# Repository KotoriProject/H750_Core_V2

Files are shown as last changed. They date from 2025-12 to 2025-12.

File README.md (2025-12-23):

# Join us!🥰🥰🥰
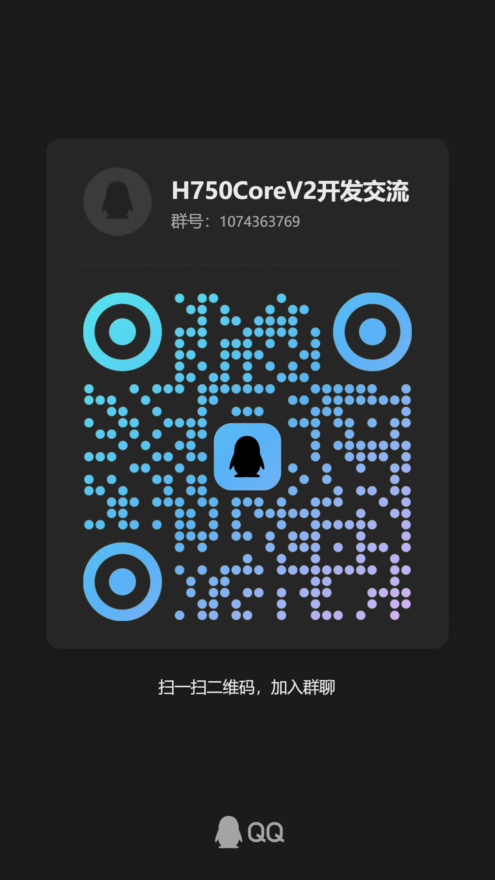
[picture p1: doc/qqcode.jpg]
qrcode
 

# STM32H750XBH6 Core V2

Feature: just mini😇only mini😡yes mini😎

lead some config/power pin like:
- PDR_ON
- BOOT0
- VREF±
- VDDA VSSA
- VCAP/VDDLDO
- VBAT

Onboard:
- 32Mbit 32bit SDRAM
- 128Mbit dual qspi flash
- HSE
- LSE
- TLV75801P external Vcap LDO

## about the mother board
[ongoing...](https://github.com/KotoriProject/H750_Core_V2_motherBoard.git)

## EDA library(Powered by Kicad)

[symbol,footprint,3Dstep](/eda_lib)

## Schematic

[Click](<doc/H750XB_V2.pdf>)

## PCB 3D
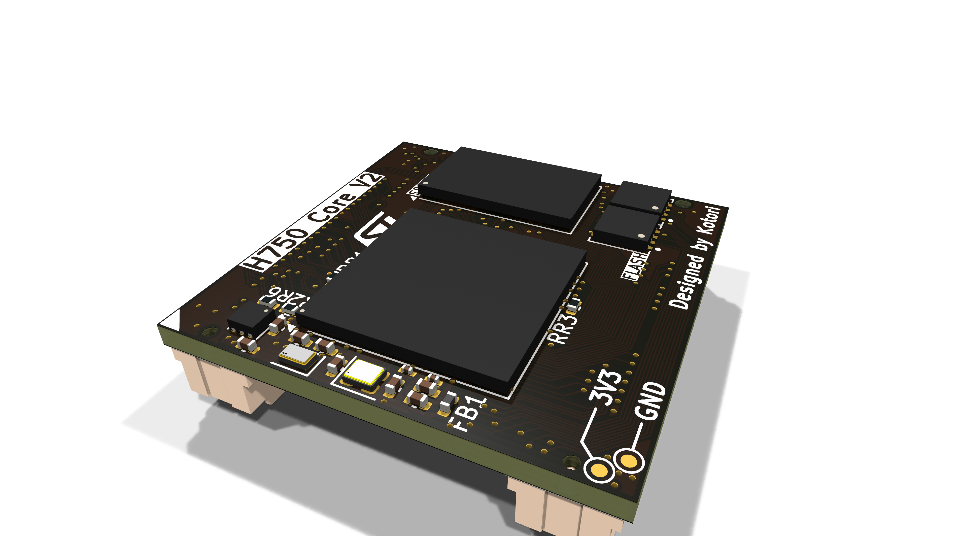
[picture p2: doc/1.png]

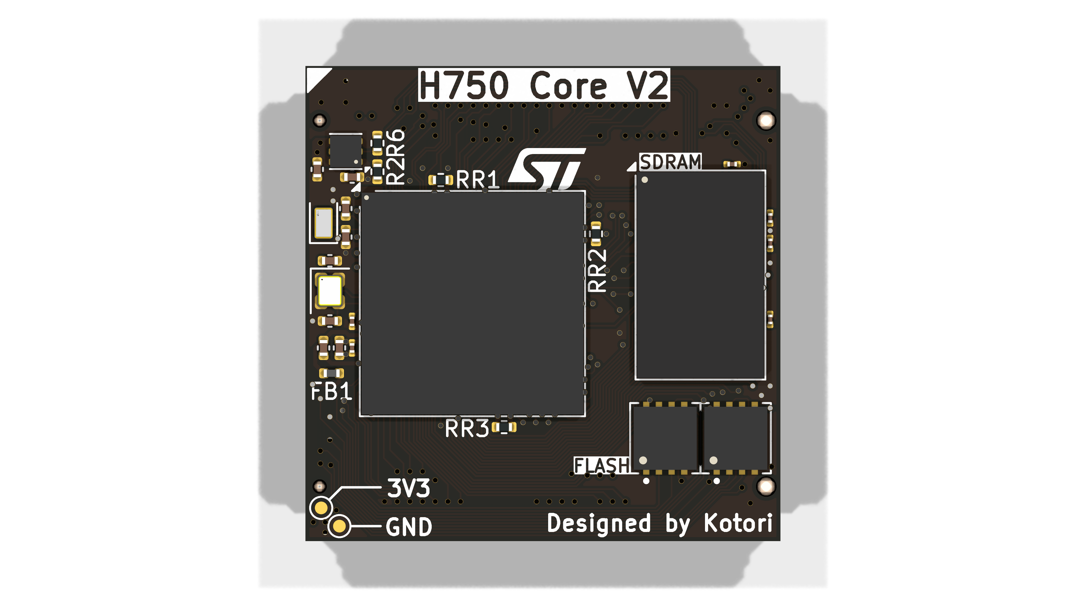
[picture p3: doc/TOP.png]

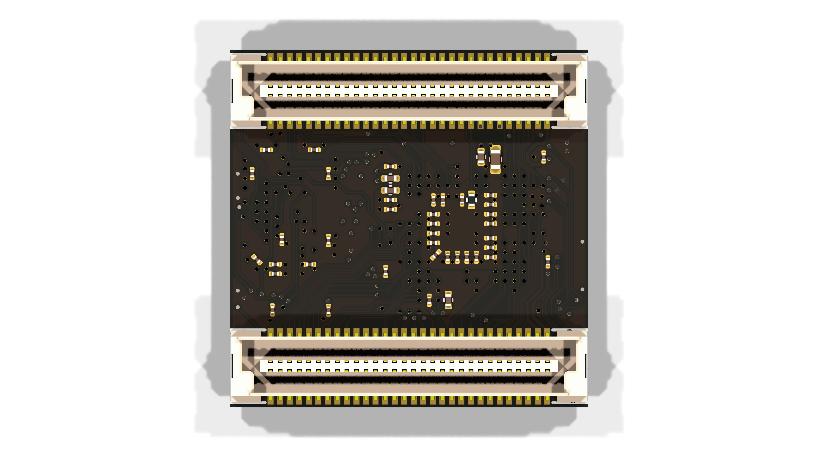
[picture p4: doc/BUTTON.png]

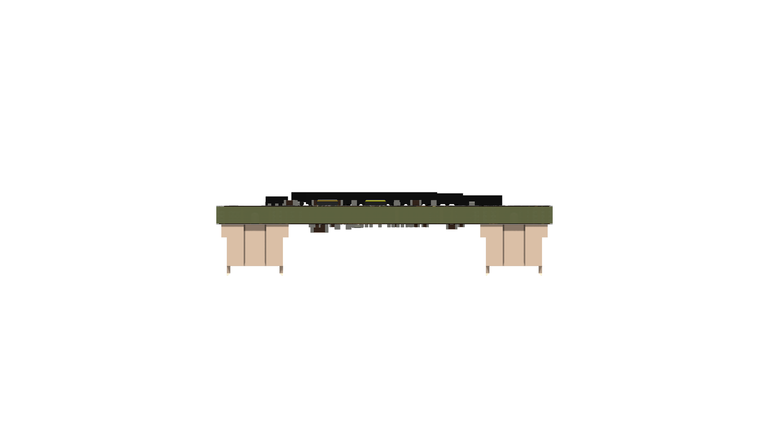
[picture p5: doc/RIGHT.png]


## Fabrication

[gerber,bom,placement](/fab)

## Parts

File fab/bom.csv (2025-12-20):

Reference | Value | Footprint | Qty
C1,C7,C10,C11,C12,C15,C16,C17,C18,C20,C21,C22,C23,C24,C25,C26,C27,C28,C29,C30,C31,C32,C33,C34,C35,C36,C37,C38,C39,C42,C43,C44,C45,C48,C49,C50,C51,C52,C53,C58,C59,C61,C62,C64 | 100nF | Capacitor_SMD:C_0201_0603Metric | 44
C3,C6,C9 | 100nF | Capacitor_SMD:C_0402_1005Metric | 3
C4,C13,C14 | 1uF | Capacitor_SMD:C_0402_1005Metric | 3
C40,C41,C46,C47 | 9pF | Capacitor_SMD:C_0402_1005Metric | 4
C60 | 4.7uF | Capacitor_SMD:C_0603_1608Metric | 1
C63,C65 | 2.2uF | Capacitor_SMD:C_0402_1005Metric | 2
CN1,CN3 | X0802WVS-60AS-LPV01 | EasyEDA_Lib:CONN-SMD_60P-P0.80_XKB_X0802WVS-60ADS-LPV01 | 2
FB1 | BLM15AX102SN1D | Inductor_SMD:L_0402_1005Metric | 1
R1 | 10k | Resistor_SMD:R_0402_1005Metric | 1
R2 | 15.4k | Resistor_SMD:R_0402_1005Metric | 1
R6 | 10.2k | Resistor_SMD:R_0402_1005Metric | 1
RR1,RR2,RR3 | 0 | Resistor_SMD:R_0402_1005Metric | 3
U1 | STM32H750XBH6 | Package_BGA:TFBGA-265_14x14mm_Layout17x17_P0.8mm | 1
U2 | IS42S32800G-6BLI | my:BGA-90_8.0x13.0mm_Layout2x3x15_P0.8mm_0.45mm | 1
U3,U4 | W25Q64JVXGIQ | kicad_api_lib:W25Q64JVXGIQ | 2
U5 | TLV75801PDRV | Package_SON:WSON-6-1EP_2x2mm_P0.65mm_EP1x1.6mm | 1
Y1 | XL7EL89CKI-111YLC-24M | Crystal:Crystal_SMD_2016-4Pin_2.0x1.6mm | 1
Y2 | X1A0000610006 | Crystal:Crystal_SMD_2012-2Pin_2.0x1.2mm | 1

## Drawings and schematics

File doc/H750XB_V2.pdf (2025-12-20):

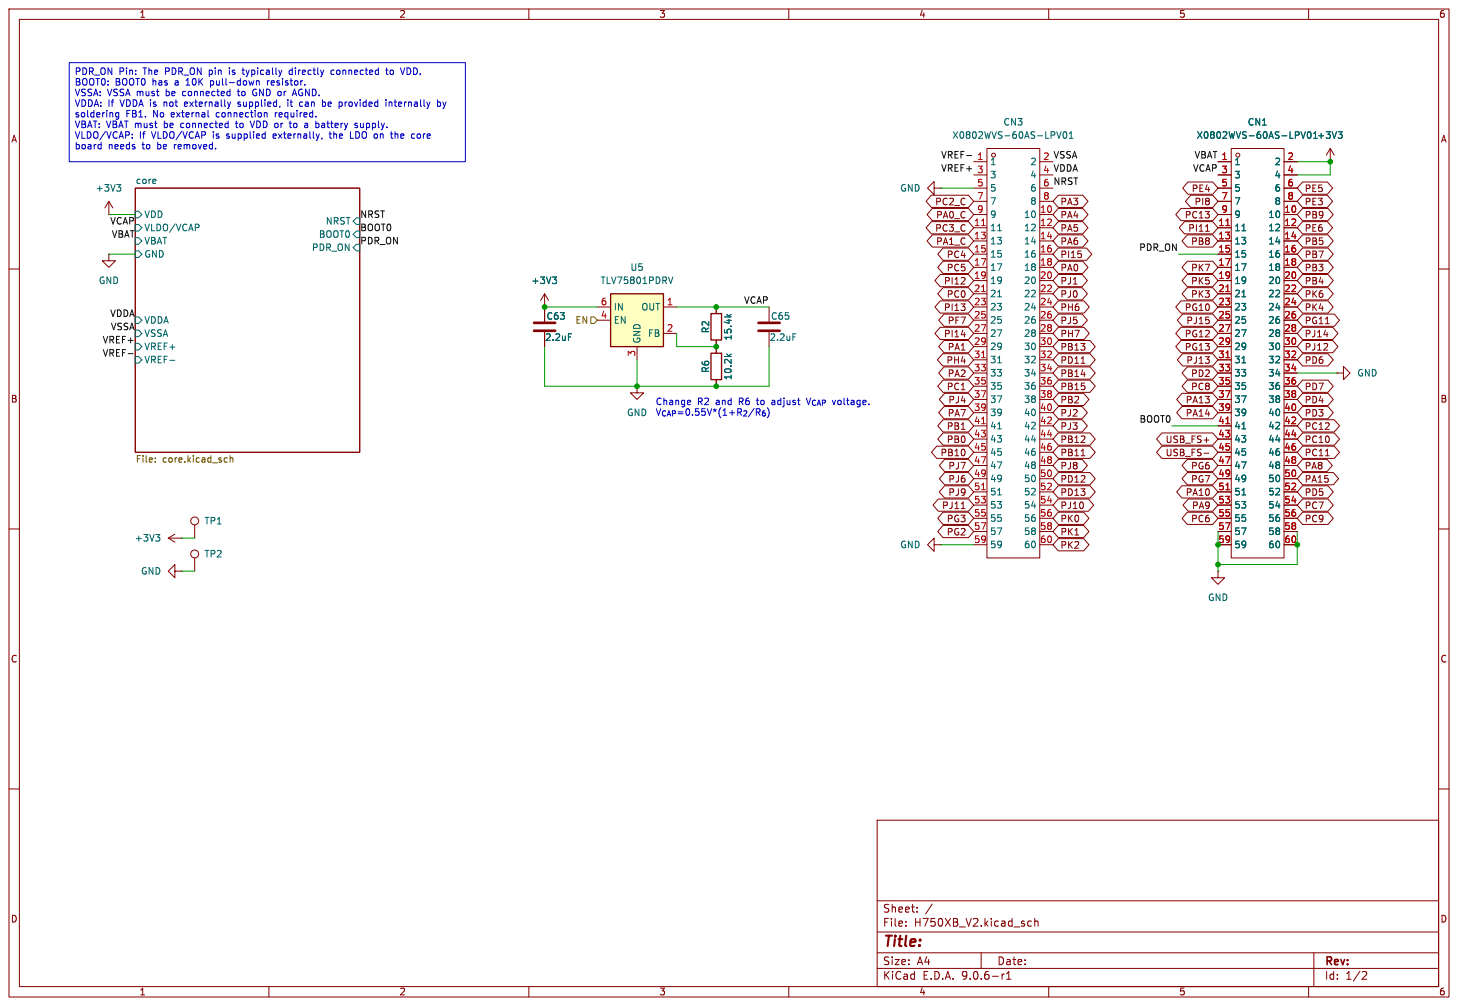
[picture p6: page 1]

Id: 1/2 Title: File: H750XB_V2.kicad_sch Sheet: /

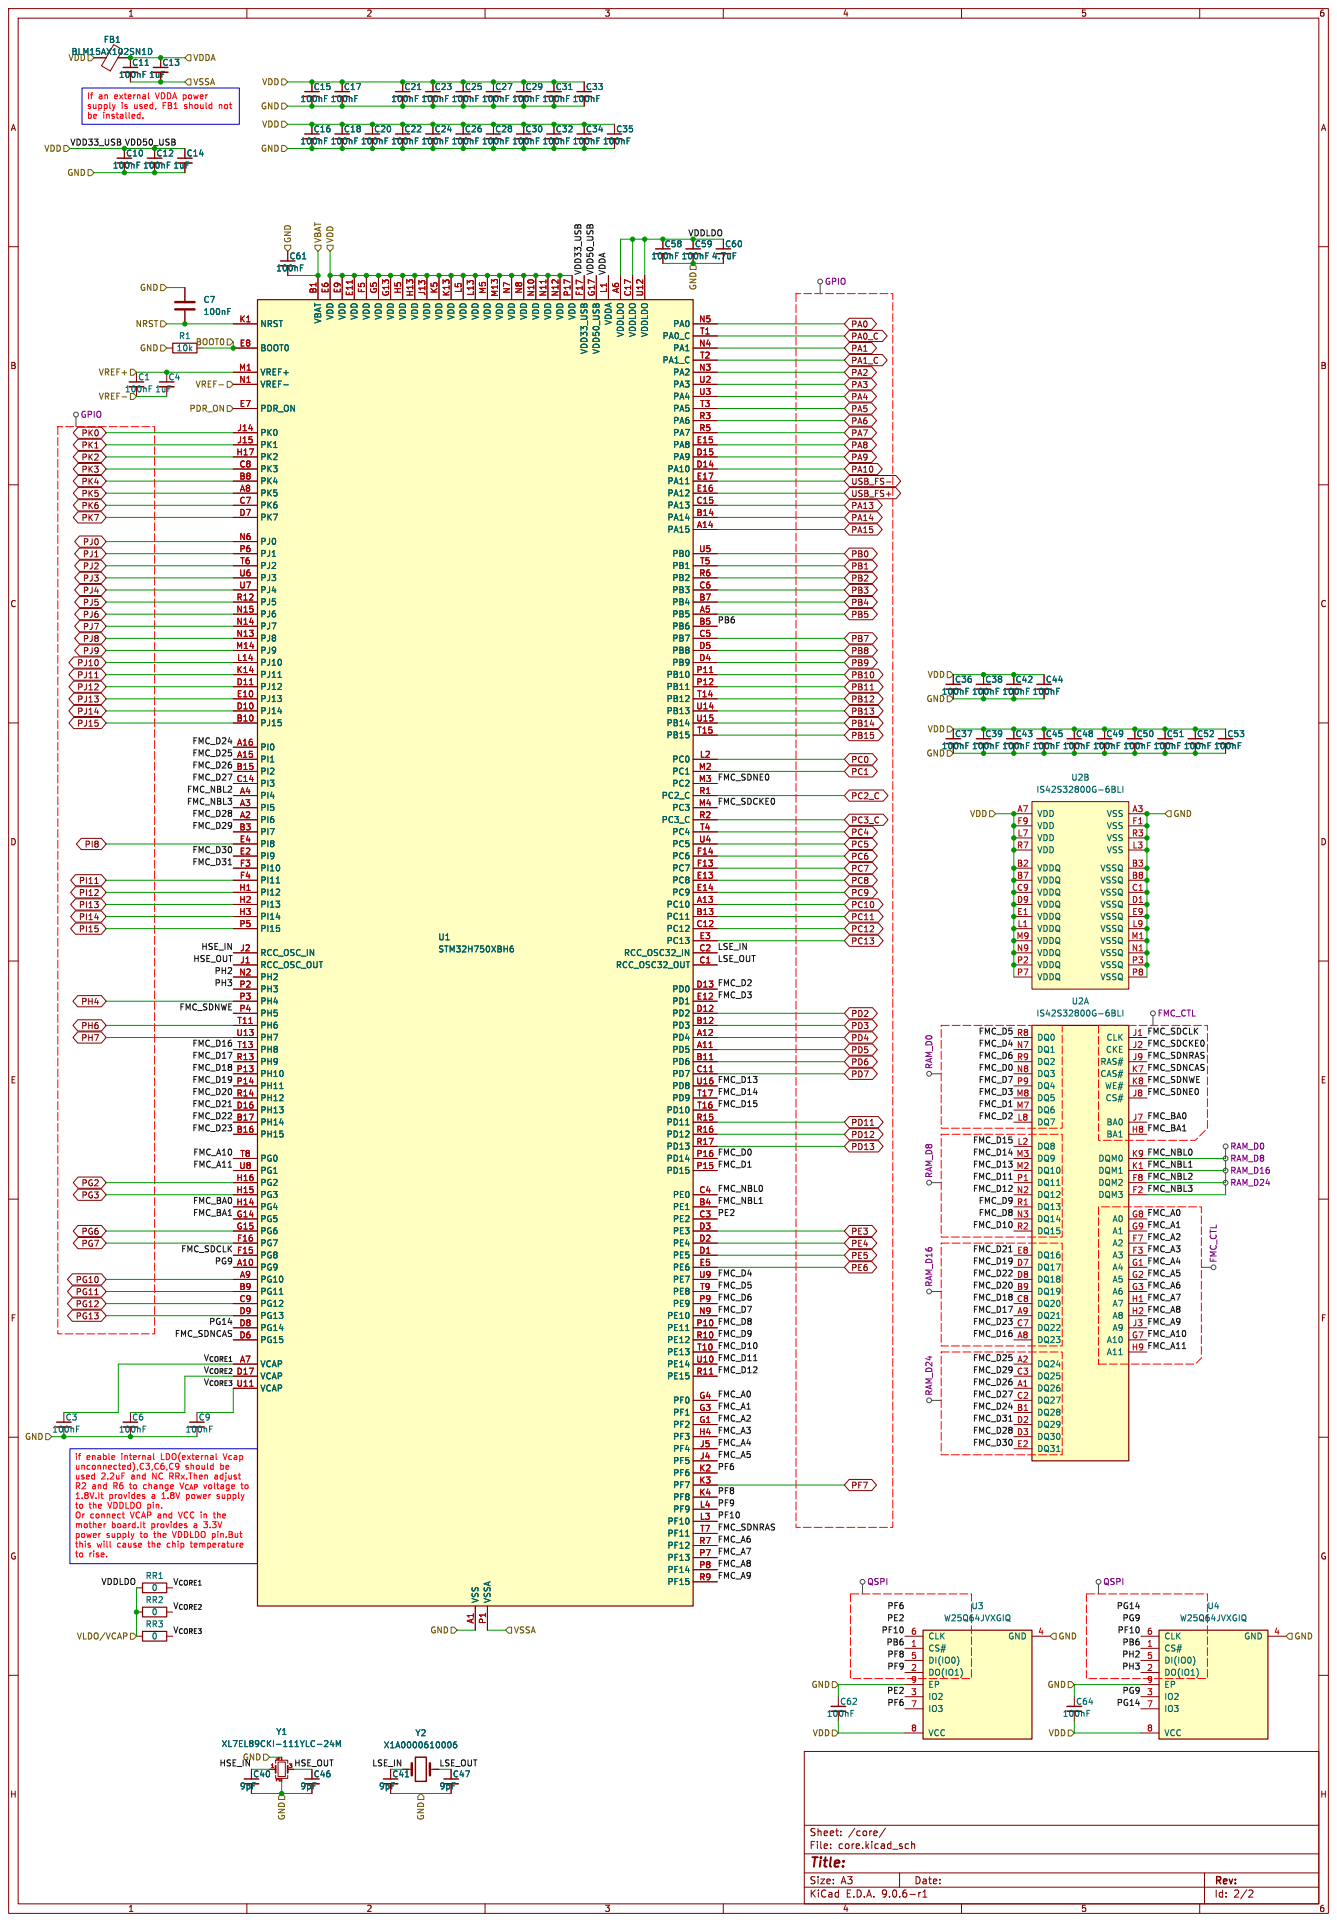
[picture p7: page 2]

used 2.2uF and NC RRx.Then adjust R2 and R6 to change V_{CAP} voltage to

1.8V.It provides a 1.8V power supply

power supply to the VDDLDO pin.But
this will cause the chip temperature
to rise.

Id: 2/2 Title: File: core.kicad_sch Sheet: /core/

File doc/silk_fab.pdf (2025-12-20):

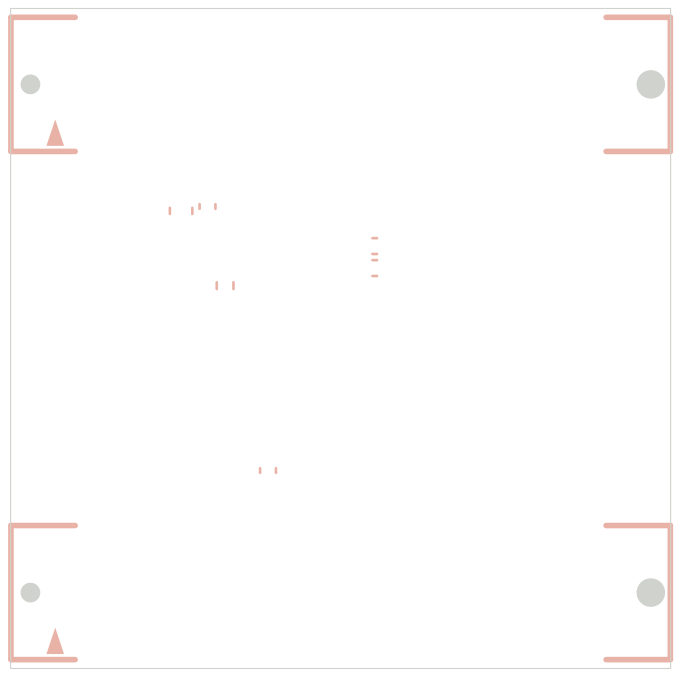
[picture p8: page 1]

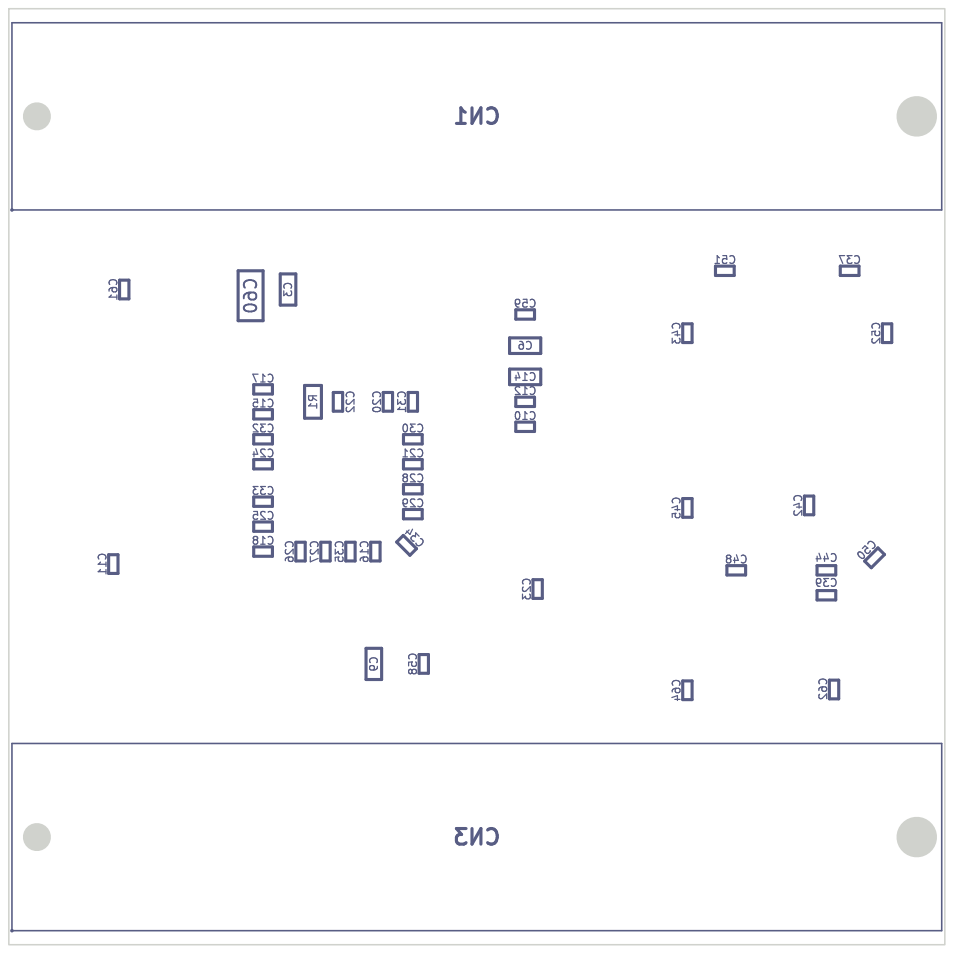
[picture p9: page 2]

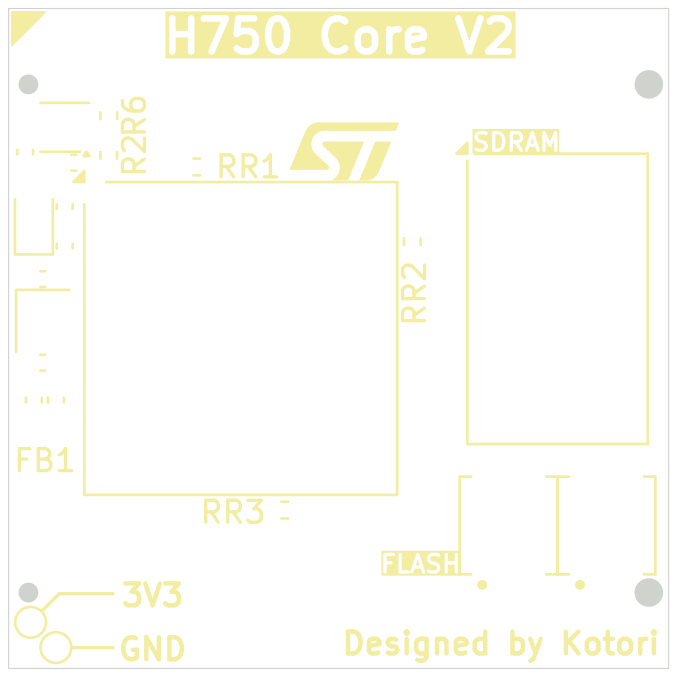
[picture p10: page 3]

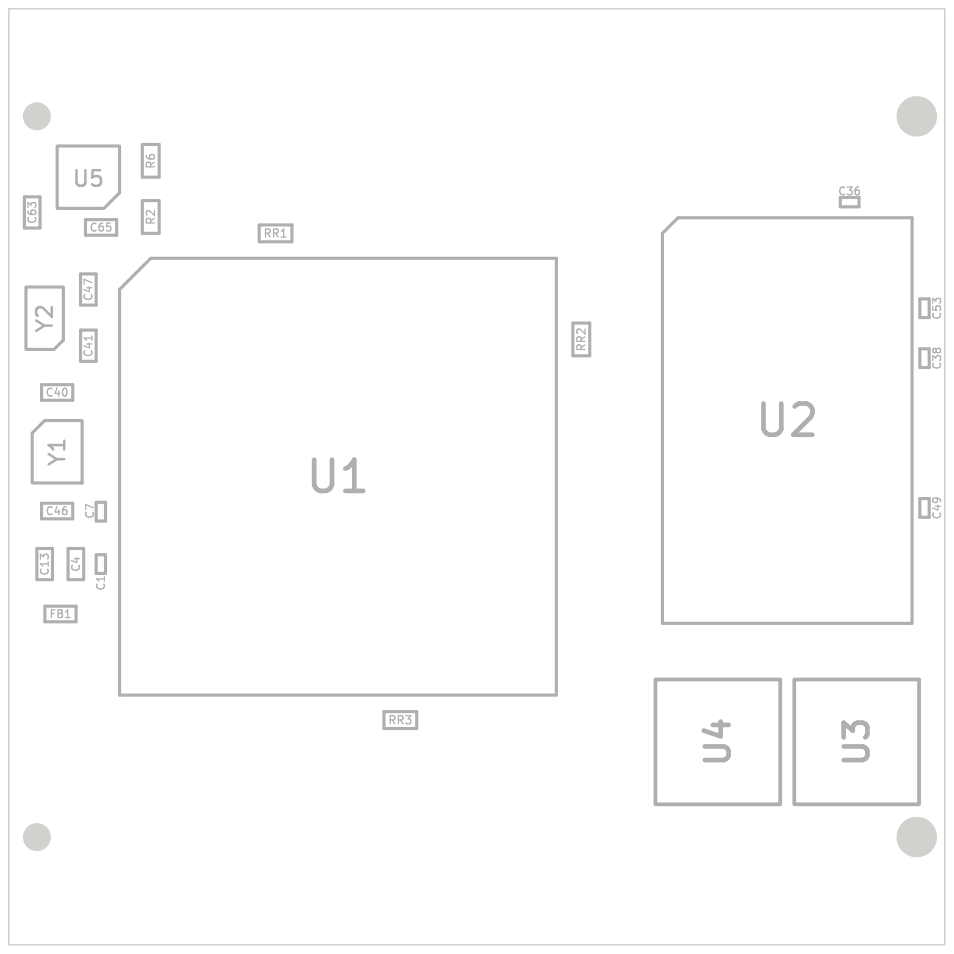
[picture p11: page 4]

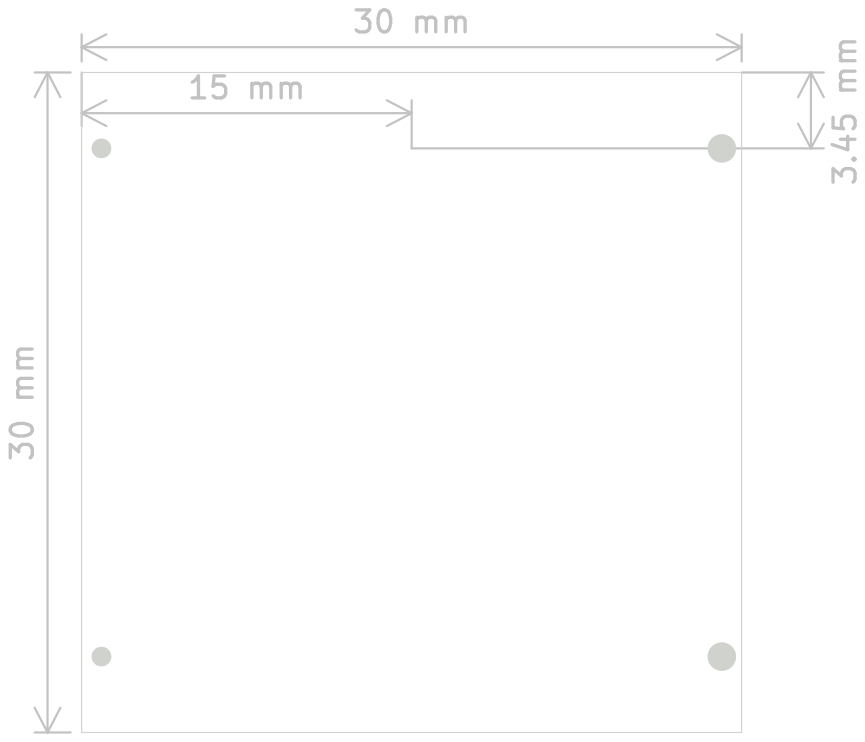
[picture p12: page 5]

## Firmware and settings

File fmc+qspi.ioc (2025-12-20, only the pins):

Mcu.UserName=STM32H750XBHx
PB6.Signal=QUADSPI_BK1_NCS
PC2.Signal=FMC_SDNE0
PC3.Signal=FMC_SDCKE0
PD0.Signal=FMC_D2_DA2
PD1.Signal=FMC_D3_DA3
PD10.Signal=FMC_D15_DA15
PD14.Signal=FMC_D0_DA0
PD15.Signal=FMC_D1_DA1
PD8.Signal=FMC_D13_DA13
PD9.Signal=FMC_D14_DA14
PE0.Signal=FMC_NBL0
PE1.Signal=FMC_NBL1
PE10.Signal=FMC_D7_DA7
PE11.Signal=FMC_D8_DA8
PE12.Signal=FMC_D9_DA9
PE13.Signal=FMC_D10_DA10
PE14.Signal=FMC_D11_DA11
PE15.Signal=FMC_D12_DA12
PE2.Signal=QUADSPI_BK1_IO2
PE7.Signal=FMC_D4_DA4
PE8.Signal=FMC_D5_DA5
PE9.Signal=FMC_D6_DA6
PF0.Signal=FMC_A0
PF1.Signal=FMC_A1
PF10.Signal=QUADSPI_CLK
PF11.Signal=FMC_SDNRAS
PF12.Signal=FMC_A6
PF13.Signal=FMC_A7
PF14.Signal=FMC_A8
PF15.Signal=FMC_A9
PF2.Signal=FMC_A2
PF3.Signal=FMC_A3
PF4.Signal=FMC_A4
PF5.Signal=FMC_A5
PF6.Signal=QUADSPI_BK1_IO3
PF8.Signal=QUADSPI_BK1_IO0
PF9.Signal=QUADSPI_BK1_IO1
PG0.Signal=FMC_A10
PG1.Signal=FMC_A11
PG14.Signal=QUADSPI_BK2_IO3
PG15.Signal=FMC_SDNCAS
PG4.Signal=FMC_A14_BA0
PG5.Signal=FMC_A15_BA1
PG8.Signal=FMC_SDCLK
PG9.Signal=QUADSPI_BK2_IO2
PH10.Signal=FMC_D18
PH11.Signal=FMC_D19
PH12.Signal=FMC_D20
PH13.Signal=FMC_D21
PH14.Signal=FMC_D22
PH15.Signal=FMC_D23
PH2.Signal=QUADSPI_BK2_IO0
PH3.Signal=QUADSPI_BK2_IO1
PH5.Signal=FMC_SDNWE
PH8.Signal=FMC_D16
PH9.Signal=FMC_D17
PI0.Signal=FMC_D24
PI1.Signal=FMC_D25
PI10.Signal=FMC_D31
PI2.Signal=FMC_D26
PI3.Signal=FMC_D27
PI4.Signal=FMC_NBL2
PI5.Signal=FMC_NBL3
PI6.Signal=FMC_D28
PI7.Signal=FMC_D29
PI9.Signal=FMC_D30
